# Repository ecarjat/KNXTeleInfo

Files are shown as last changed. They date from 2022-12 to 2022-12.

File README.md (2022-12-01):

# **French energy provider Enedis TeleInfo (TIC) KNX interface.**

Compatible with Enedis Linky meters in "Historic" mode, and "Blue" meters.

This is a fork of [etrinh software](https://github.com/etrinh/TeleInfoKNX) whose original design can be bought [here](https://www.tindie.com/products/zdi/knx-teleinfo/) 

This fork uses Raspberry [RP2040](https://www.raspberrypi.com/products/rp2040/) with a 64M-bit Serial Flash Memory and has a USB B Micro port to update the firmware.

# Firmware

The firmware has been refactored to split classes into their own files and adapt it to the rp2040.
It also leverages the latest version (as of 01/12/22) of [KNX Library](https://github.com/thelsing/knx) and in particular it's support for RP2040.

## **Features:**
- Activatable RealTime mode for real-time consumption monitoring/display.
- History of total Consumption (Current Year, Current Month, Today, Last Year, Last Month, Yesterday) (an external KNX Clock participant is required to provide accurate date and time).
- ETS5 configurable.
- Bus powered (10mA).

## **Usage:**
- Connect the device to the TeleInfo terminals (I1 I2) on the energy meter (No polarity).
- Connect the device to the KNX bus.
- To activate the device Programming Mode, click the "PROG / HRST".
- Configure device in ETS.
- To reset History, press the History Reset "PROG / HRST" Button more than 4 seconds.
- In case of over-current warning, the message "Depassement" (Group Object 43) is repeated every 10 seconds on the bus.

## **Led Interpretation:**
- Led Blinking (0.5s On/1.5s Off): TeleInfo data are receiving - **Device is working properly**.
- Led Continuously On: The device is in programming mode (it will automatically switch off after a delay of 15 minutes or a new press on the "PROG / HRST" button).
- Led Blinking (0.5s On/0.5s Off): The History is erased (happens when the "PROG / HRST" Button is pressed during more than 4 seconds).
- Led Off: The device is not receiving TeleInfo data, or is not configured with ETS5, or is not connected to the KNX Bus.

## **Group Objects:**
All "Consumption" Group Objects (from GO 7 to GO 24):

- Can be read to get the consumption index difference from the beginning and ending of the specified period.
- Can be written by the consumption index at the beginning of the corresponding period. It allows to specifically initialize the history from data provided by your energy provider. It is advised to set these indexes before affecting monitoring participants to these Group Objects.

## **Product Database:**
Click [here](https://github.com/etrinh/TeleInfoKNX/raw/master/ETS/teleinfo.knxprod) to download ETS5 product database (identified as KNX Association).

# Firmware upload
The Firmware can be uploaded directly through the USB port. On MacOS The firmware upload can be done by uncommenting this line in platform.io:
```
;upload_port = /Volumes/RPI-RP2/
```
This leverages the rp2040 embedded boot firmware. If the drive does not show pushing the reset button on the main board (SW3) while plugging in the usb should make it appear.
Once the firmware has been uploaded once, the serial port should become available.

# Hardware

## Sources
The hardware is build from a set of open source designs
[Adafruit ItsyBitsy rp2040](https://github.com/adafruit/Adafruit-ItsyBitsy-RP2040-PCB)
[Nano BCU](https://gitlab.com/knx-makerstuff/knx_microbcu2/-/wikis/NanoBCU)
[PiTInfo](https://github.com/hallard/teleinfo/tree/master/PiTInfo)
cobbled together on a board that needs to be cut in three parts and assembled.

## Geting the hardware

The folder hardware contain the kicad files and the gerber/bom/cpl files that can be sent to [JLCPCB](https://jlcpcb.com/).
The fabrication output is a board 

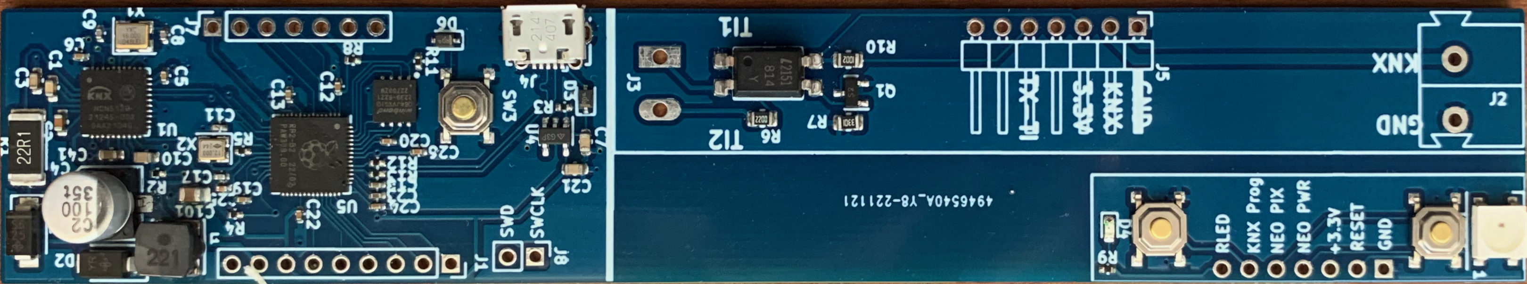
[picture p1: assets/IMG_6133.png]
[](assets/IMG_6133.png)

## Hardware assembly

The board then needs to be cut in three parts.

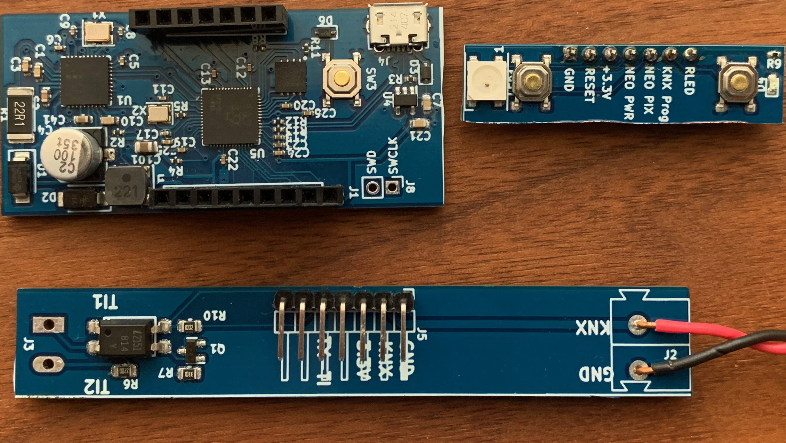
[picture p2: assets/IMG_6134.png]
[](assets/IMG_6134.png)

The assembly should be fairly self explanatory with teh silk screen. There are two unsused pins on the main board reserver for future use.

Once assembled the board looks like this

[](assets/IMG_6135.png)

And fits into a [DIN Rail Box Size 1 from RS PRO](https://docs.rs-online.com/575c/A700000006545717.pdf). This can be ordered [here](https://fr.rs-online.com/web/p/boitiers-rail-din/1947577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).

## Remarks

The NeoPixel on the top board is not used by this application and is not powered by the firmware.

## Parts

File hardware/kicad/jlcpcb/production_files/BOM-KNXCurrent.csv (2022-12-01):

Comment | Designator | Footprint | LCSC
16Mhz | X1 | Crystal_SMD_3225-4Pin_3.2x2.5mm | C13738
100nF/50V | C3 | C_0603_1608Metric | C14663
AP2112K-3.3 | U4 | SOT-23-5 | C51118
TVS SMA40 | D2 | D_SMA | C513490
1K | R11,R5,R9 | R_0402_1005Metric | C11702
LTV-814 | U2 | OPTO-SMD4 | C125118
NCN5120MNTWG | U1 | QFN-40-1EP_6x6mm_P0.5mm_EP4.6x4.6mm | C130364
USB_B_Micro | J4 | USB_Micro-B_Molex-105017-0001 | C136000
100nF/6.3V | C5,C6 | C_0402_1005Metric | C1525
18pF/50V | C11,C17 | C_0402_1005Metric | C1549
1uF/50V | C41 | C_0603_1608Metric | C15849
10uF/6.3V | C101 | C_0805_2012Metric | C15850
47nF/50V | C1 | C_0603_1608Metric | C1622
10K | R10 | R_0805_2012Metric | C17414
220R | R6 | R_0805_2012Metric | C17557
SS16 | D1 | D_SMA | C183023
RP2040 | U5 | QFN-56-1EP_7x7mm_P0.4mm_EP3.2x3.2mm | C2040
Red | D4 | D_0603_1608Metric | C2286
100uF/35V | C4 | CP_Elec_6.3x5.7 | C249982
22R | R12,R13 | R_0402_1005Metric | C25092
10k | R3,R4,R8 | R_0402_1005Metric | C25744
3K3 | R7 | R_0805_2012Metric | C26010
CJ2302 | Q1 | SOT-23 | C2910175
WS2812B3535 | LED1 | LED_WS2812B_PLCC4_5.0x5.0mm_P3.2mm | C2920042
W25Q64JVXGIQ | IC1 | SON80P400X400X50-9N | C2940195
100nF/50V | C12,C13,C19,C20,C22,C24,C25,C26 | C_0402_1005Metric | C307331
RESET | SW1,SW2,SW3 | SW_TS-1187A-B-A-B | C318884
10pF/50V | C8,C9 | C_0402_1005Metric | C32949
1R | R2 | R_0402_1005Metric | C332612
22R | R1 | R_2512_6332Metric | C421606
NSR0320 | D3,D6 | D_SOD-323 | C48192
220uH | L1 | IND_VLS5045EX-3R3N | C501936
12MHz | X2 | Crystal_SMD_2520-4Pin_2.5x2.0mm | C521567
1uF/25V | C18,C23 | C_0402_1005Metric | C52923
4.7nF/50V | C2 | C_0603_1608Metric | C53987
10uF/25V | C10,C21,C7 | C_0603_1608Metric | C96446
Debug | J8 | PinHeader_1x02_P2.54mm_Vertical
Conn_01x07_Male | J5 | PinHeader_1x07_P2.54mm_Horizontal
Conn_01x07_Female | J7 | PinSocket_1x07_P2.54mm_Vertical
KNX | J2 | KNX Male
Screw_Terminal_01x02 | J3 | TerminalBlock_Altech_AK300-2_P5.00mm
Conn_01x09_Female | J1 | PinSocket_1x09_P2.54mm_Vertical
Conn_01x07_Male | J6 | PinHeader_1x07_P2.54mm_Horizontal
SolderJumper_3_Bridged12 | JP2 | SolderJumper-3_P1.3mm_Bridged2Bar12_RoundedPad1.0x1.5mm_NumberLabels
Save to D11 | JP1 | SolderJumper-2_P1.3mm_Open_RoundedPad1.0x1.5mm

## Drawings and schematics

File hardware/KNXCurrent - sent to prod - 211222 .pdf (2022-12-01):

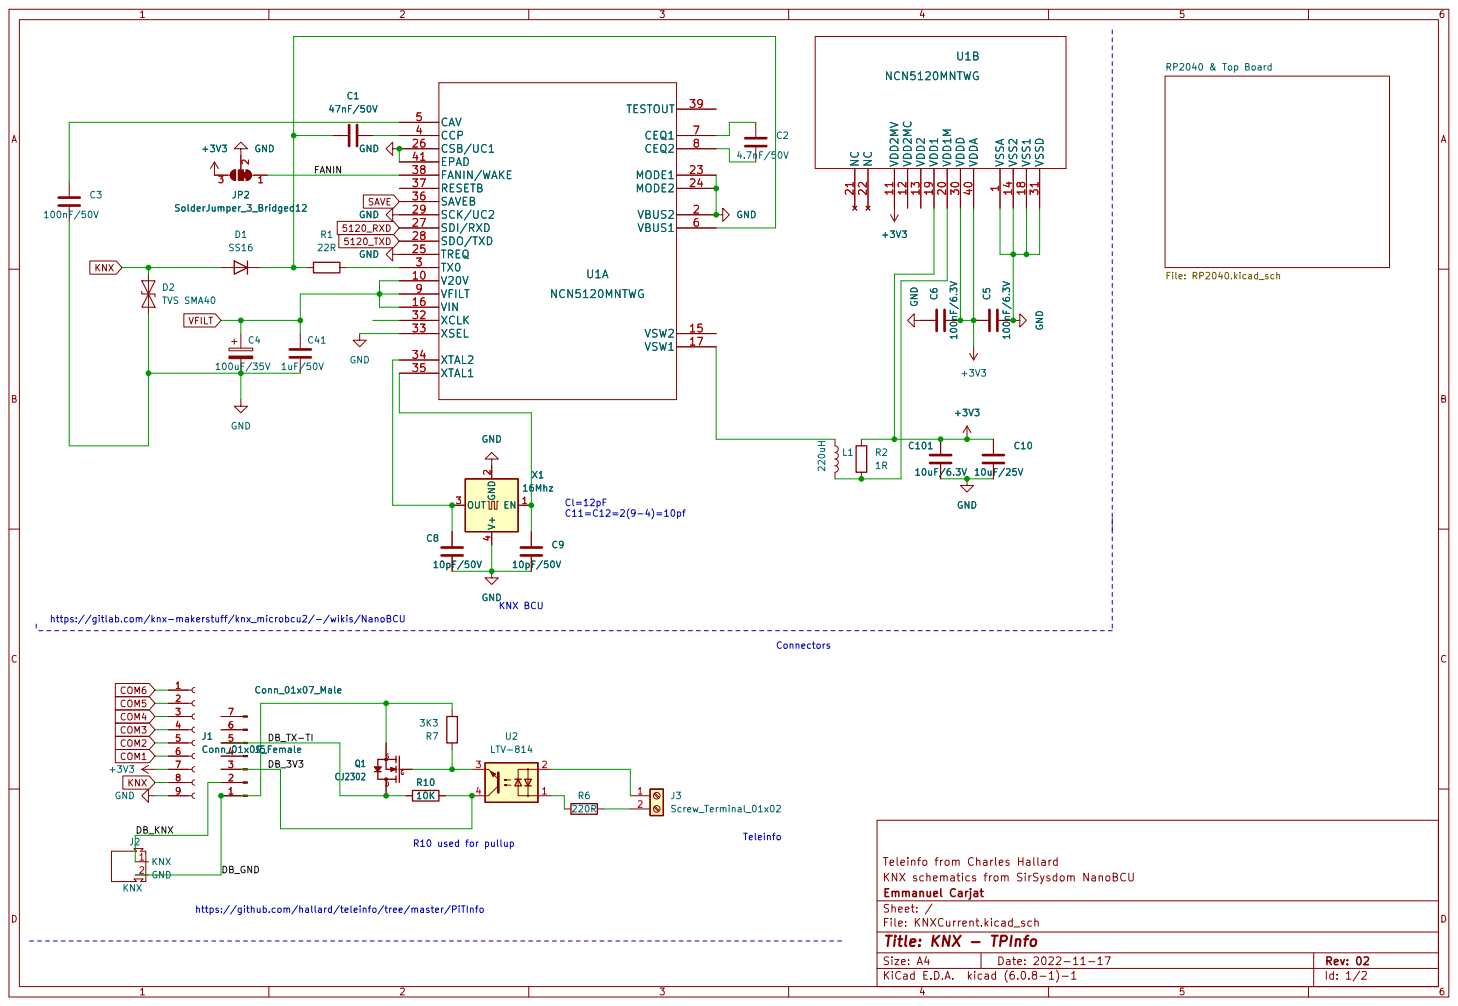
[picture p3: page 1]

1 VDD2MV 11 VDD2MC 12 VDD2 13 VSS2 14 VSS1 18 VDD1 19 VDD1M 20 NC 21 NC 22 VDDD 30 VSSD 31 VDDA 40 U1B NCN5120MNTWG

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

https://gitlab.com/knx-makerstuff/knx_microbcu2/-/wikis/NanoBCU

Teleinfo from Charles Hallard
KNX schematics from SirSysdom NanoBCU
File: KNXCurrent.kicad_sch Sheet: / Emmanuel Carjat

https://github.com/hallard/teleinfo/tree/master/PiTInfo

Id: 1/2 Title: KNX - TPInfo

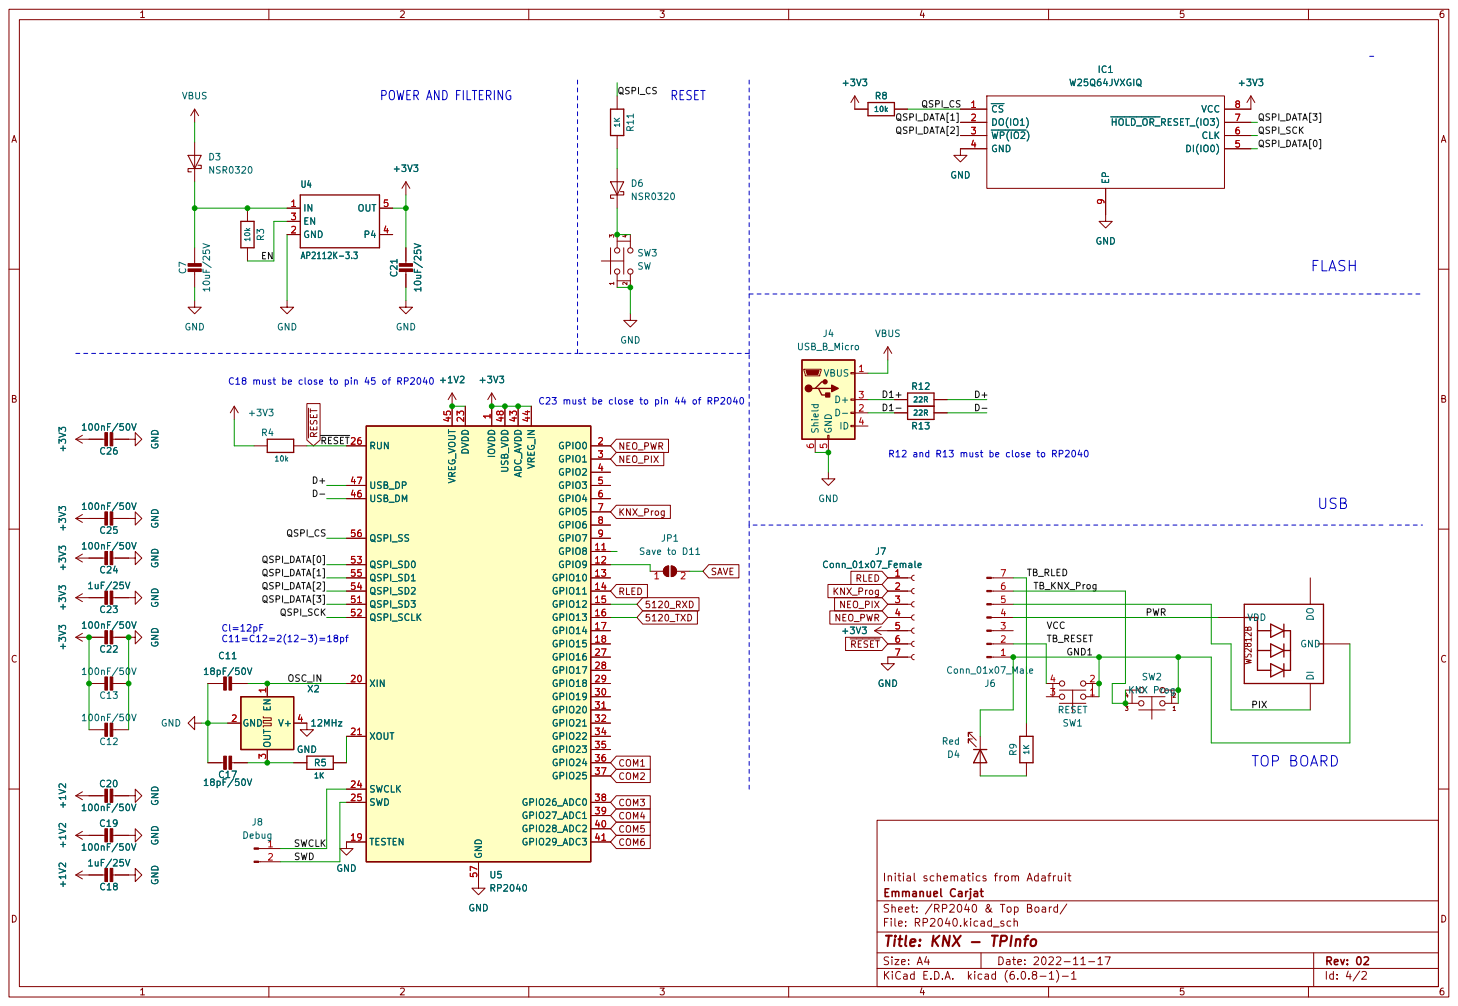
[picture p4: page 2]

C18 must be close to pin 45 of RP2040

C23 must be close to pin 44 of RP2040

1 GPIO8 11 GPIO9 12 GPIO10 13 GPIO11 14 GPIO12 15 GPIO13 16 GPIO14 17 GPIO15 18 TESTEN 19 GPIO0 2 XIN 20 XOUT 21 DVDD 23 SWCLK 24 SWD 25 RUN 26 GPIO16 27 GPIO17 28 GPIO18 29 GPIO1 3 GPIO19 30 GPIO20 31 GPIO21 32 GPIO22 34 GPIO23 35 GPIO24 36 GPIO25 37 GPIO26_ADC0 38 GPIO27_ADC1 39 GPIO2 4 GPIO28_ADC2 40 GPIO29_ADC3 41 ADC_AVDD 43 VREG_IN 44 VREG_VOUT 45 USB_DM 46 USB_DP 47 USB_VDD 48 GPIO3 5 QSPI_SD3 51 QSPI_SCLK 52 QSPI_SD0 53 QSPI_SD2 54 QSPI_SD1 55 QSPI_SS 56 GND 57 GPIO4 6 GPIO5 7 GPIO6 8 GPIO7 9 GND GND

1 GPIO8 11 GPIO9 12 GPIO10 13 GPIO11 14 GPIO12 15 GPIO13 16 GPIO14 17 GPIO15 18 TESTEN 19 GPIO0 2 XIN 20 XOUT 21 DVDD 23 SWCLK 24 SWD 25 RUN 26 GPIO16 27 GPIO17 28 GPIO18 29 GPIO1 3 GPIO19 30 GPIO20 31 GPIO21 32 GPIO22 34 GPIO23 35 GPIO24 36 GPIO25 37 GPIO26_ADC0 38 GPIO27_ADC1 39 GPIO2 4 GPIO28_ADC2 40 GPIO29_ADC3 41 ADC_AVDD 43 VREG_IN 44 VREG_VOUT 45 USB_DM 46 USB_DP 47 USB_VDD 48 GPIO3 5 QSPI_SD3 51 QSPI_SCLK 52 QSPI_SD0 53 QSPI_SD2 54 QSPI_SD1 55 QSPI_SS 56 GND 57 GPIO4 6 GPIO5 7 GPIO6 8 GPIO7 9 U5RP2040 R91K

Initial schematics from Adafruit C19

Emmanuel Carjat
Sheet: /RP2040 & Top Board/
File: RP2040.kicad_sch
Id: 4/2 Title: KNX - TPInfo

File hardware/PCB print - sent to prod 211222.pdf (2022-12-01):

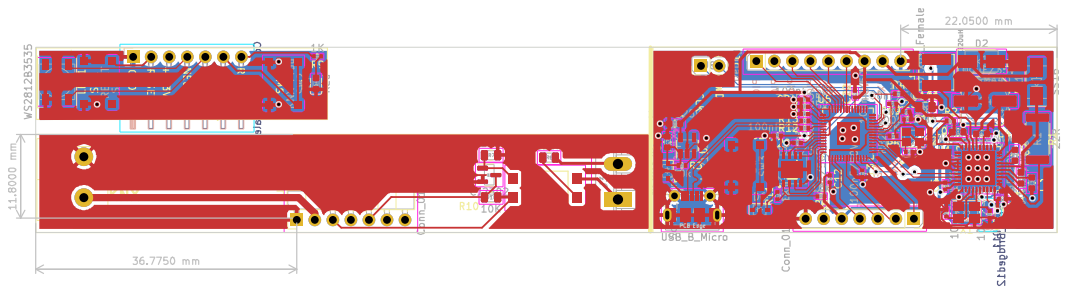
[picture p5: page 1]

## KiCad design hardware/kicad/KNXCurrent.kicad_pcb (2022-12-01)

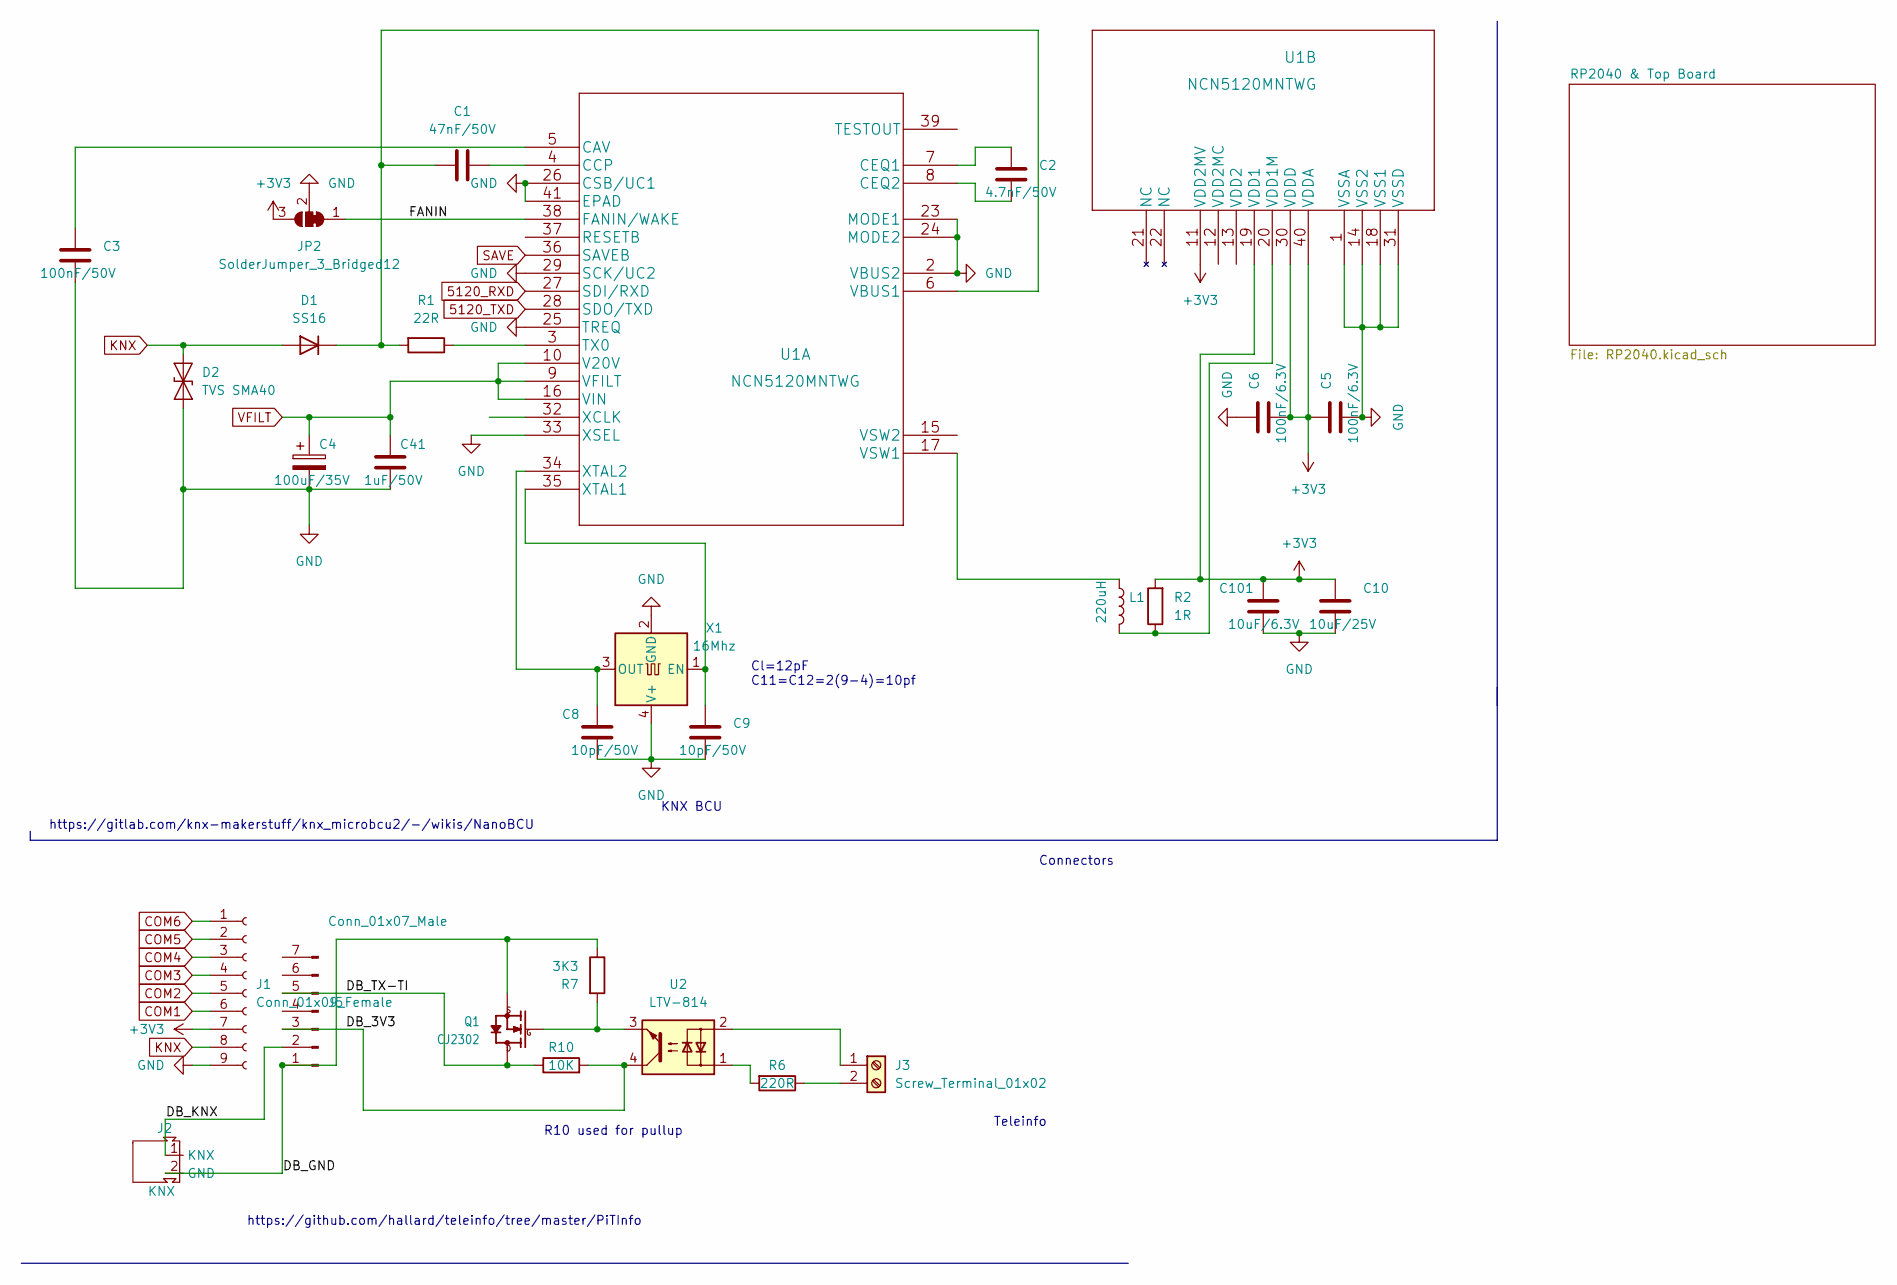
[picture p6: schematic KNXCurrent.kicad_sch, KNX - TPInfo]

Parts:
C1: 47nF/50V; C_0603_1608Metric; LCSC C1622
C2: 4.7nF/50V; C_0603_1608Metric; LCSC C53987
C3: 100nF/50V; C_0603_1608Metric; LCSC C14663
C4: 100uF/35V; CP_Elec_6.3x5.7; LCSC C249982
C5, C6: 100nF/6.3V; C_0402_1005Metric; LCSC C1525
C8, C9: 10pF/50V; C_0402_1005Metric; LCSC C32949
C10: 10uF/25V; C_0603_1608Metric; LCSC C96446
C41: 1uF/50V; C_0603_1608Metric; LCSC C15849
C101: 10uF/6.3V; C_0805_2012Metric; LCSC C15850
D1: SS16; D_SMA; LCSC C183023
D2: TVS SMA40; D_SMA; LCSC C513490
J1: Conn_01x09_Female; PinSocket_1x09_P2.54mm_Vertical
J2: KNX; KNX Male
J3: Screw_Terminal_01x02; TerminalBlock_Altech_AK300-2_P5.00mm
J5: Conn_01x07_Male; PinHeader_1x07_P2.54mm_Horizontal
JP2: SolderJumper_3_Bridged12; SolderJumper-3_P1.3mm_Bridged2Bar12_RoundedPad1.0x1.5mm_Num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
L1: 220uH; IND_VLS5045EX-3R3N; LCSC C501936
Q1: CJ2302; SOT-23; LCSC C2910175
R1: 22R; R_2512_6332Metric; LCSC C421606
R2: 1R; R_0402_1005Metric; LCSC C332612
R6: 220R; R_0805_2012Metric; LCSC C17557
R7: 3K3; R_0805_2012Metric; LCSC C26010
R10: 10K; R_0805_2012Metric; LCSC C17414
U1: NCN5120MNTWG; QFN-40-1EP_6x6mm_P0.5mm_EP4.6x4.6mm; LCSC C130364
U2: LTV-814; OPTO-SMD4; LCSC C125118
X1: 16Mhz; Crystal_SMD_3225-4Pin_3.2x2.5mm; LCSC C13738

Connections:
5120_RXD: U1.27 (SDI/RXD); also elsewhere on the board
5120_TXD: U1.28 (SDO/TXD); also elsewhere on the board
+3V3: C5.1, C6.2, C10.1, C101.1, J1.7, JP2.3 (B), R2.2, U1.11 (VDD2MV), U1.19 (VDD1), U1.30 (VDDD), U1.40 (VDDA); also elsewhere on the board
/DB_3V3: J5.3, R10.2, U2.4
/DB_GND: J2.2 (GND), J5.1, Q1.2 (S), R7.1
/DB_KNX: J2.1 (KNX), J5.2
/DB_TX-TI: J5.5, Q1.3 (D), R10.1
/FANIN: JP2.1 (A), U1.38 (FANIN/WAKE)
COM1: J1.6; also elsewhere on the board
COM2: J1.5; also elsewhere on the board
COM3: J1.4; also elsewhere on the board
COM4: J1.3; also elsewhere on the board
COM5: J1.2; also elsewhere on the board
COM6: J1.1; also elsewhere on the board
GND: C3.2, C4.2, C5.2, C6.1, C8.2, C9.2, C10.2, C41.2, C101.2, D2.2 (A2), J1.9, JP2.2 (C), U1.1 (VSSA), U1.2 (VBUS2), U1.14 (VSS2), U1.18 (VSS1), U1.23 (MODE1), U1.24 (MODE2), U1.25 (TREQ), U1.26 (CSB/UC1), U1.29 (SCK/UC2), U1.31 (VSSD), U1.33 (XSEL), U1.41 (EPAD), X1.2 (GND), X1.4 (V+); also elsewhere on the board
KNX: D1.2 (A), D2.1 (A1), J1.8
unnamed: C1.1, D1.1 (K), R1.2, U1.6 (VBUS1)
unnamed: C1.2, U1.4 (CCP)
unnamed: C2.1, U1.7 (CEQ1)
unnamed: C2.2, U1.8 (CEQ2)
unnamed: C3.1, U1.5 (CAV)
unnamed: C8.1, U1.34 (XTAL2), X1.3 (OUT)
unnamed: C9.1, U1.35 (XTAL1), X1.1 (EN)
unnamed: J3.1, U2.2
unnamed: J3.2, R6.1
unnamed: L1.1, U1.17 (VSW1)
unnamed: L1.2, R2.1, U1.20 (VDD1M)
unnamed: Q1.1 (G), R7.2, U2.3
unnamed: R1.1, U1.3 (TX0)
unnamed: R6.2, U2.1
SAVE: U1.36 (SAVEB); also elsewhere on the board
VFILT: C4.1, C41.1, U1.9 (VFILT), U1.10 (V20V), U1.16 (VIN)

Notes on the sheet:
Connectors
R10 used for pullup
https://github.com/hallard/teleinfo/tree/master/PiTInfo
Teleinfo
Cl=12pF C11=C12=2(9-4)=10pf
KNX BCU
https://gitlab.com/knx-makerstuff/knx_microbcu2/-/wikis/NanoBCU

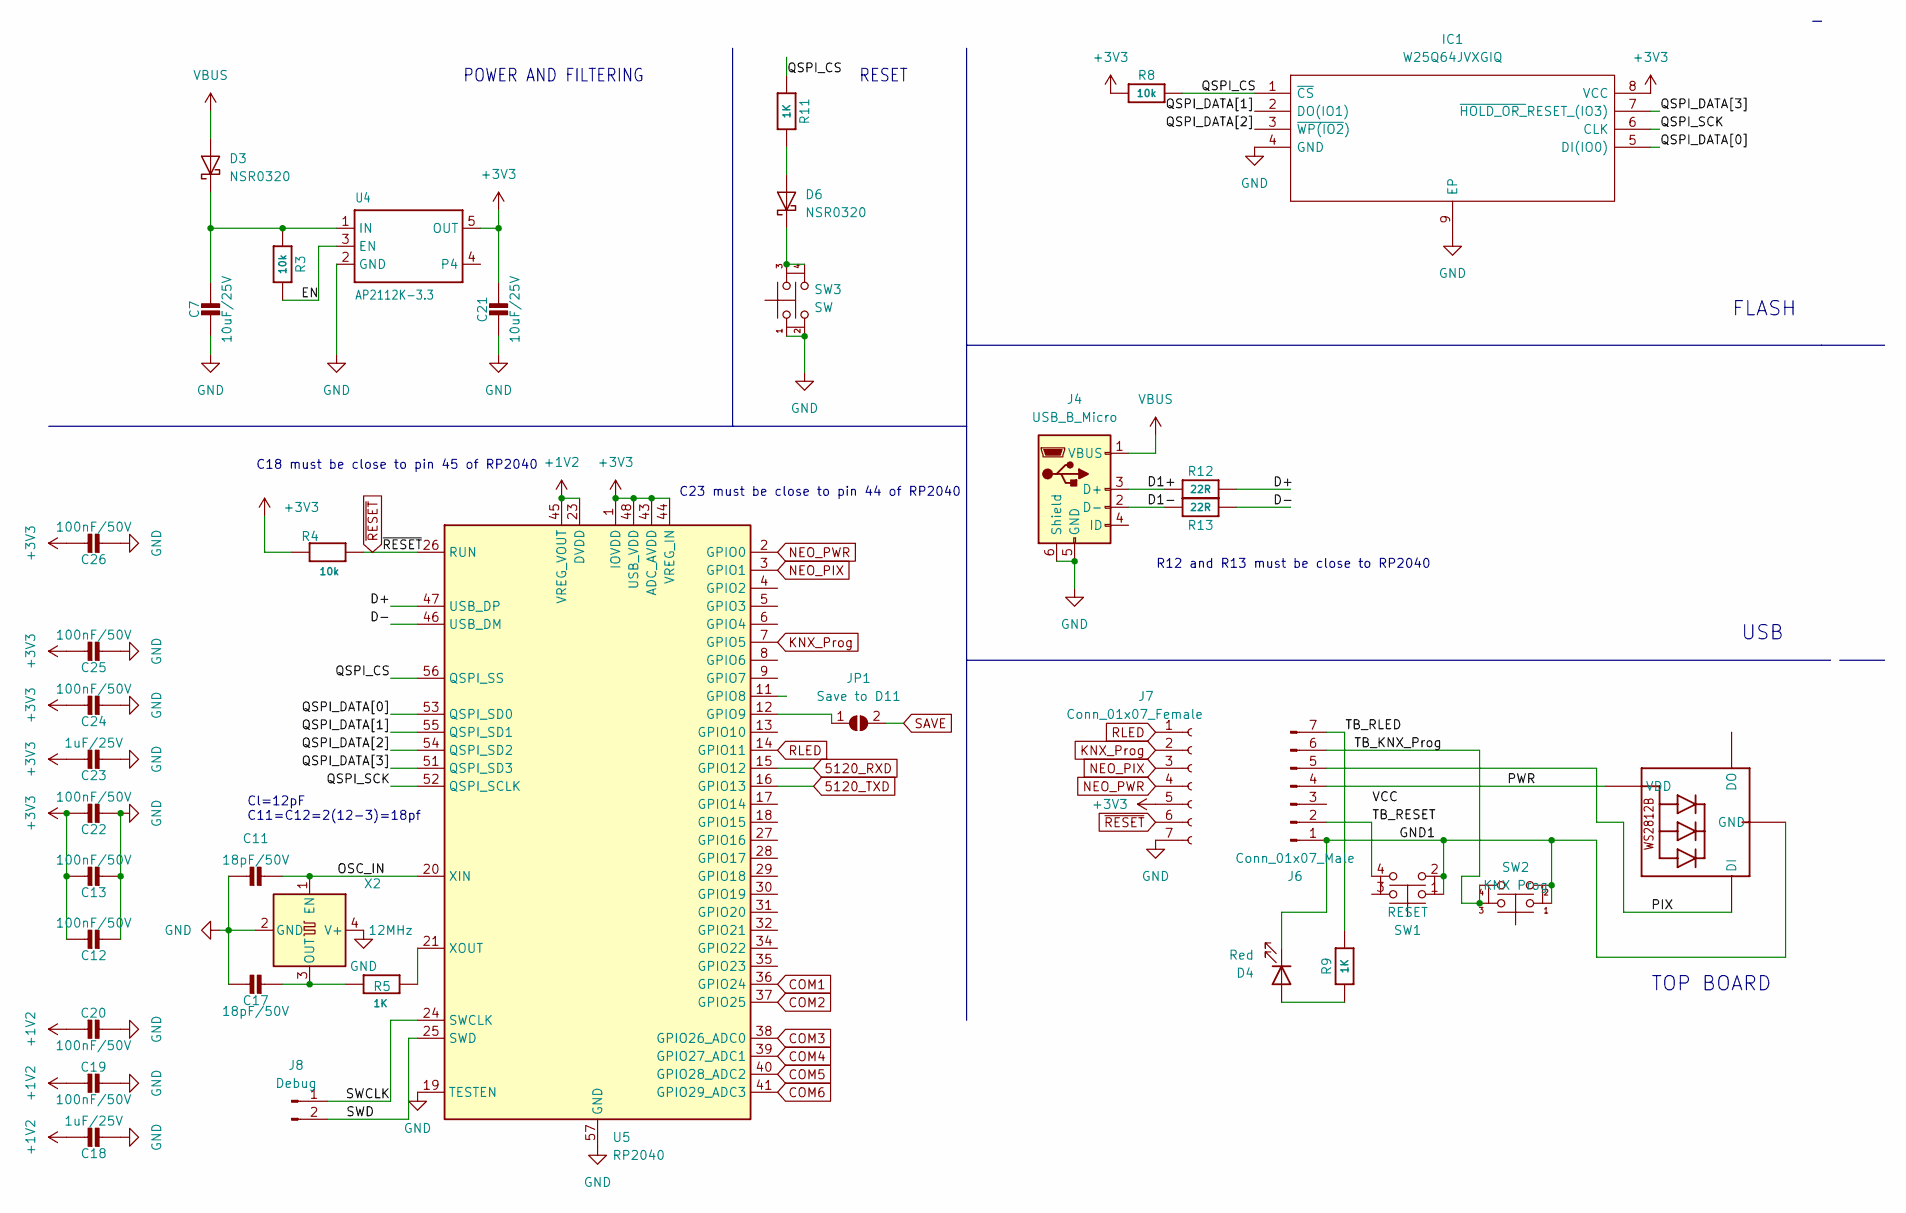
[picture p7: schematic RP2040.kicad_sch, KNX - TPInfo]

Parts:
C7, C21: 10uF/25V; C_0603_1608Metric; LCSC C96446
C11, C17: 18pF/50V; C_0402_1005Metric; LCSC C1549
C12, C13, C19, C20, C22, C24, C25, C26: 100nF/50V; C_0402_1005Metric; LCSC C307331
C18, C23: 1uF/25V; C_0402_1005Metric; LCSC C52923
D3, D6: NSR0320; D_SOD-323; LCSC C48192
D4: Red; D_0603_1608Metric; LCSC C2286
IC1: W25Q64JVXGIQ; SON80P400X400X50-9N; Manufacturer_Part_Number W25Q64JVXGIQ; LCSC C2940195
J4: USB_B_Micro; USB_Micro-B_Molex-105017-0001; LCSC C136000
J6: Conn_01x07_Male; PinHeader_1x07_P2.54mm_Horizontal
J7: Conn_01x07_Female; PinSocket_1x07_P2.54mm_Vertical
J8: Debug; PinHeader_1x02_P2.54mm_Vertical
JP1: Save to D11; SolderJumper-2_P1.3mm_Open_RoundedPad1.0x1.5mm
LED1: WS2812B3535; LED_WS2812B_PLCC4_5.0x5.0mm_P3.2mm; LCSC C2920042
R3, R4, R8: 10k; R_0402_1005Metric; LCSC C25744
R5, R9, R11: 1K; R_0402_1005Metric; LCSC C11702
R12, R13: 22R; R_0402_1005Metric; LCSC C25092
SW1: RESET; SW_TS-1187A-B-A-B; LCSC C318884
SW2: KNX Prog; SW_TS-1187A-B-A-B; LCSC C318884
SW3: SW; SW_TS-1187A-B-A-B; LCSC C318884
U4: AP2112K-3.3; SOT-23-5; LCSC C51118
U5: RP2040; QFN-56-1EP_7x7mm_P0.4mm_EP3.2x3.2mm; LCSC C2040
X2: 12MHz; Crystal_SMD_2520-4Pin_2.5x2.0mm; LCSC C521567

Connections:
5120_RXD: U5.15 (GPIO12); also elsewhere on the board
5120_TXD: U5.16 (GPIO13); also elsewhere on the board
+1V2: C18.1, C19.2, C20.2, U5.23 (DVDD), U5.45 (VREG_VOUT), U5.50 (DVDD)
+3V3: C12.1, C13.1, C21.1, C22.1, C23.1, C24.1, C25.1, C26.1, IC1.8 (VCC), J7.5, R4.1, R8.1, U4.5 (OUT), U5.1 (IOVDD), U5.10 (IOVDD), U5.22 (IOVDD), U5.33 (IOVDD), U5.42 (IOVDD), U5.43 (ADC_AVDD), U5.44 (VREG_IN), U5.48 (USB_VDD), U5.49 (IOVDD); also elsewhere on the board
/RP2040 & Top Board/D1+: J4.3 (D+), R12.1
/RP2040 & Top Board/D1-: J4.2 (D-), R13.1
/RP2040 & Top Board/D+: R12.2, U5.47 (USB_DP)
/RP2040 & Top Board/D-: R13.2, U5.46 (USB_DM)
/RP2040 & Top Board/EN: R3.2, U4.3 (EN)
/RP2040 & Top Board/GND1: D4.1 (K), J6.1, LED1.3 (GND), SW1.1, SW1.2, SW2.1, SW2.2
/RP2040 & Top Board/OSC_IN: C11.2, U5.20 (XIN), X2.1 (EN)
/RP2040 & Top Board/PIX: J6.5, LED1.4 (DI)
/RP2040 & Top Board/PWR: J6.4, LED1.1 (VDD)
/RP2040 & Top Board/QSPI_CS: IC1.1 (~CS), R8.2, R11.1, U5.56 (QSPI_SS)
/RP2040 & Top Board/QSPI_DATA[0]: IC1.5 (DI(IO0)), U5.53 (QSPI_SD0)
/RP2040 & Top Board/QSPI_DATA[1]: IC1.2 (DO(IO1)), U5.55 (QSPI_SD1)
/RP2040 & Top Board/QSPI_DATA[2]: IC1.3 (~WP(IO2)), U5.54 (QSPI_SD2)
/RP2040 & Top Board/QSPI_DATA[3]: IC1.7 (~HOLD_OR_RESET_(IO3)), U5.51 (QSPI_SD3)
/RP2040 & Top Board/QSPI_SCK: IC1.6 (CLK), U5.52 (QSPI_SCLK)
/RP2040 & Top Board/SWCLK: J8.1, U5.24 (SWCLK)
/RP2040 & Top Board/SWD: J8.2, U5.25 (SWD)
/RP2040 & Top Board/TB_KNX_Prog: J6.6, SW2.3, SW2.4
/RP2040 & Top Board/TB_RESET: J6.2, SW1.4
/RP2040 & Top Board/TB_RLED: J6.7, R9.2
COM1: U5.36 (GPIO24); also elsewhere on the board
COM2: U5.37 (GPIO25); also elsewhere on the board
COM3: U5.38 (GPIO26_ADC0); also elsewhere on the board
COM4: U5.39 (GPIO27_ADC1); also elsewhere on the board
COM5: U5.40 (GPIO28_ADC2); also elsewhere on the board
COM6: U5.41 (GPIO29_ADC3); also elsewhere on the board
GND: C7.2, C11.1, C12.2, C13.2, C17.1, C18.2, C19.1, C20.1, C21.2, C22.2, C23.2, C24.2, C25.2, C26.2, IC1.4 (GND), IC1.9 (EP), J4.5 (GND), J4.6 (Shield), J7.7, SW3.1, SW3.2, U4.2 (GND), U5.19 (TESTEN), U5.57 (GND), X2.2 (GND), X2.4 (V+); also elsewhere on the board
KNX_Prog: J7.2, U5.7 (GPIO5)
NEO_PIX: J7.3, U5.3 (GPIO1)
NEO_PWR: J7.4, U5.2 (GPIO0)
unnamed: C7.1, D3.1 (K), R3.1, U4.1 (IN)
unnamed: C17.2, R5.1, X2.3 (OUT)
unnamed: D4.2 (A), R9.1
unnamed: D6.1 (K), SW3.3, SW3.4
unnamed: D6.2 (A), R11.2
unnamed: JP1.1 (A), U5.12 (GPIO9)
unnamed: R5.2, U5.21 (XOUT)
RLED: J7.1, U5.14 (GPIO11)
SAVE: JP1.2 (B); also elsewhere on the board
VBUS: D3.2 (A), J4.1 (VBUS)
~RESET: J7.6, R4.2, U5.26 (RUN)

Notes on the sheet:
C23 must be close to pin 44 of RP2040
POWER AND FILTERING
R12 and R13 must be close to RP2040
USB
C18 must be close to pin 45 of RP2040
TOP BOARD
Cl=12pF C11=C12=2(12-3)=18pf
FLASH
RESET

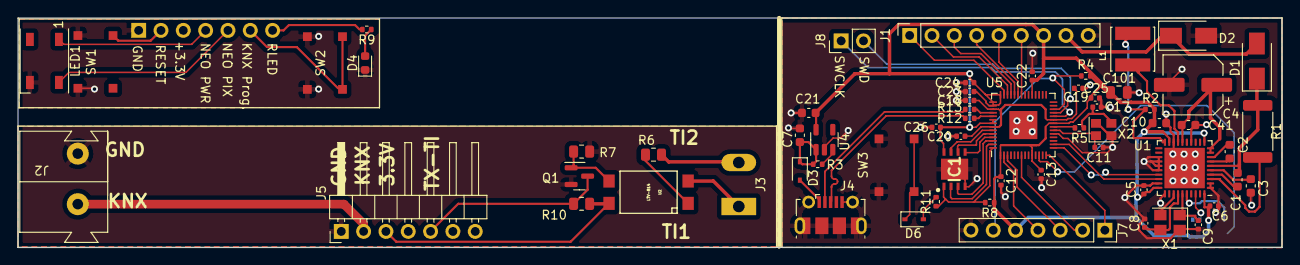
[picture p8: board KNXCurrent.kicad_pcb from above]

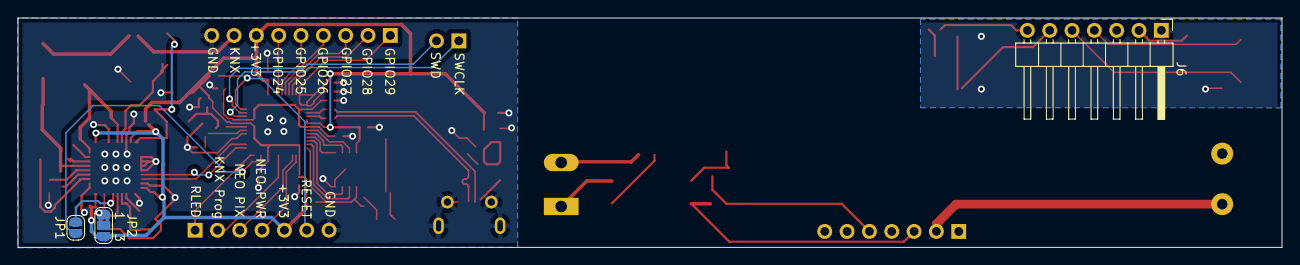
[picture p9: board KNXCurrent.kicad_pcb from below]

Board: 2 copper layers, 143.8 x 26.1 mm, 66 parts (3 on the bottom side), 66 nets.

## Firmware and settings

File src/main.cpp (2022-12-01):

/*
 * TeleInfo KNX
 *  Can be used with French TeleInfo systems
 *  Compatible with Linky in "Historic" mode and "Blue" electric meters
 *  GPL-3.0 License
 * Copyright 2020-2021 ZapDesign Innovative - Author: Eric Trinh
 */

#include <Arduino.h>
#include <knx.h>

#include <hardware/uart.h>

#include <pico/stdlib.h>
#include <hardware/pll.h>
#include <hardware/clocks.h>
#include <hardware/structs/pll.h>
#include <hardware/structs/clocks.h>

#include "RTCKnx.h"
#include "TeleInfo.h"

#define VERSION_MAJOR 1
#define VERSION_MINOR 0
#define VERSION_REVISION 0

#define PIN_PROG_SWITCH 5
#define PIN_PROG_LED 11
#define PROG_TIMEOUT (15 * 60 * 1000) // 15 mins
#define PIN_TPUART_RX 13              // stm32 knx uses Serial2 (pins 16,17)
#define PIN_TPUART_TX 12

#define TELEINFO_UART_SPEED 1200        //
#define TELEINFO_UART_CONFIG SERIAL_7E1 // SERIAL_7E1
#define TELEINFO_UART_RX 25
#define TELEINFO_UART_TX 24

#define HISTORY_RESET_PROG_SWITCH_DELAY 4000  // 4s
#define HISTORY_RESET_LED_BLINKING_PERIOD 512 // 0.512s
#define RECEPTION_LED_BLINKING_PERIOD 512     // 0.512s

// Restore ram after reset (brownout)
#define INIT_MASK 0x12345678
volatile uint32_t Inited __attribute__((section(".noinit")));

uint8_t rtcHolder[sizeof(RTCKnx)] __attribute__((section(".noinit")));
RTCKnx &rtc = *(RTCKnx *)rtcHolder;

uint8_t teleinfoHolder[sizeof(TeleInfo)] __attribute__((section(".noinit")));
TeleInfo &teleinfo = *(TeleInfo *)teleinfoHolder;

extern "C" void SystemClock_Config(void)
{
    // Nothing for default 4MHz MSI Clock
    // Required to downclock the 80MHz clock to be below 4096 * 16 * 1200 (TeleInfo BaudRate) due to limitation in UART_BRR 12bit register
}

static SerialUART serialTpuart(uart0, PIN_TPUART_TX, PIN_TPUART_RX);
static SerialUART serialTeleInfo(uart1, TELEINFO_UART_TX, TELEINFO_UART_RX);

void setup()
{

    // Serial.begin(115200);
    // ArduinoPlatform::SerialDebug = &Serial;
    // while(!Serial){
    //      delay(10);
    //  }
    //  delay(300);
    //  Serial.println("Loading ....");

    if (Inited != INIT_MASK)
    {
        new (&rtc) RTCKnx();
        new (&teleinfo) TeleInfo(&rtc, &serialTeleInfo, TELEINFO_UART_SPEED, TELEINFO_UART_CONFIG);
        Inited = INIT_MASK;
    }

   


    knx.platform().knxUart(&serialTpuart);
    knx.ledPin(PIN_PROG_LED);
    knx.ledPinActiveOn(HIGH);
    knx.buttonPin(PIN_PROG_SWITCH);


    // Init device
    knx.version((VERSION_MAJOR << 6) | (VERSION_MINOR & 0x3F)); // PID_VERSION
    knx.orderNumber((const uint8_t *)"ZDI-TINFO1");             // PID_ORDER_INFO
    knx.manufacturerId(0xfa);                                   // PID_SERIAL_NUMBER (2 first bytes) - 0xfa for KNX Association
    knx.hardwareType((const uint8_t *)"M-07B0");                // PID_HARDWARE_TYPE

    // read adress table, association table, groupobject table and parameters from eeprom
    knx.readMemory();
    
    if (knx.configured())
    {
        rtc.init(0, 0);
        teleinfo.init(RTCKnx::SIZEPARAMS, RTCKnx::NBGO);
        rtc.setNotifier(std::bind(&TeleInfo::newDate, &teleinfo, std::placeholders::_1));
        // attachInterrupt(PIN_TPUART_SAVE, std::bind(&TeleInfo::saveHistory, &teleinfo), LOW);    // 2ms to save history before shutdown - likely not enough
    }

    // start the framework.
    knx.start();

}

int led = false;
bool progButtonState;
void loop()
{
    
    // don't delay here too much. Otherwise you might loose packages or mess up the timing with ETS
    knx.loop();
    // only run the application code if the device was configured with ETS
    if (knx.configured())
    {
        teleinfo.loop();
        rtc.loop();
    }
    

    uint32_t currentMillis = rtc.millis();
    PinStatus prog_pin = digitalRead(PIN_PROG_SWITCH);
    if(prog_pin == HIGH){
        progButtonState = false;
    }
    else {
        progButtonState = true;
    }


        // Handle Reset History by long prog button press
        static uint32_t progButtonPressedTimer = 0;
        static bool historyReset = false;

        if (!progButtonState && currentMillis - progButtonPressedTimer > 200) {
            progButtonPressedTimer = 0;
            if (historyReset) {
                digitalWrite(PIN_PROG_LED, LOW);
            }
            historyReset = false;
        }
        else {
            if (progButtonPressedTimer == 0) {
                progButtonPressedTimer = currentMillis;
            }
            else {
                uint32_t delay = currentMillis - progButtonPressedTimer;
                if (delay > HISTORY_RESET_PROG_SWITCH_DELAY) {
                    if (!historyReset) {
                        knx.progMode(false);
                        teleinfo.resetHistory();
                        historyReset = true;
                    }
                    if (historyReset) {
                        digitalWrite(PIN_PROG_LED, (delay/HISTORY_RESET_LED_BLINKING_PERIOD)&1);
                    }
                }
            }
        }

        // Handle Prog Mode timeout
        static uint32_t timerProgMode = 0;
        if (knx.progMode()) {
            if (timerProgMode == 0) {
                timerProgMode = currentMillis;
            }
            else {
                if (currentMillis - timerProgMode > PROG_TIMEOUT) {
                    knx.progMode(false);
                    timerProgMode = 0;
                }
            }
        }
        else {
            timerProgMode = 0;
        }


    // Handle reception blinking led (2s cycle with 0.5s On while receiving Teleinfo data)
    
    if (!knx.progMode() && !progButtonState)
    {
        //Serial.println(currentMillis - teleinfo.lastReception());
        if (currentMillis - teleinfo.lastReception() < RECEPTION_LED_BLINKING_PERIOD * 2)
        {
            digitalWrite(PIN_PROG_LED, ((currentMillis / RECEPTION_LED_BLINKING_PERIOD) & 3) == 0);
        }
        else
        {
            digitalWrite(PIN_PROG_LED, LOW);
        }
    }
    
}

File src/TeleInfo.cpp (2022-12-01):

#include <Arduino.h>
#include <knx.h>
#include <EEPROM.h>
#include "TeleInfo.h"

#define FOURCC(a, b, c, d) (((((uint32_t)(a)) << 24) | (((uint32_t)(b)) << 16) | (((uint32_t)(c)) << 8) | (d)))

TeleInfo::TeleInfo(RTCKnx *_rtc, SerialUART *suart, unsigned long _baud, uint16_t _config) : mSerial(*suart), rtc(*_rtc)
{
    speed = _baud;
    config = _config;
}

KNXValue TeleInfo::value(const TeleInfo::TeleInfoDataStruct &val)
{
    switch (val.conf->type)
    {
    default:
    case TeleInfoDataType::INT:
        return KNXValue(val.value.num);
    case TeleInfoDataType::STRING:
        return KNXValue(val.value.str);
    case TeleInfoDataType::OPTARIF:
        switch (val.value.num & 0xffffff00)
        {
        case FOURCC('B', 'A', 'S', 0) /*BASE*/:
        default:
            return KNXValue((uint8_t)0);
        case FOURCC('H', 'C', '.', 0) /*HC..*/:
            return KNXValue((uint8_t)1);
        case FOURCC('E', 'J', 'P', 0) /*EJP.*/:
            return KNXValue((uint8_t)2);
        case FOURCC('B', 'B', 'R', 0) /*BBRx*/:
            return KNXValue((uint8_t)(val.value.num & 0x3f));
            //                                  - Bit 5: toujours 1
            //                                  - Bit 4-3: programme circuit 1: 01-11 _ programme A-C
            //                                  - Bit 2-0: programme circuit 2: 000-111 _ programme P0-P7
        }
    case TeleInfoDataType::PTEC:
        switch (val.value.num)
        {
        case FOURCC('T', 'H', '.', '.') /*Toutes les Heures*/:
        default:
            return KNXValue((uint8_t)0);
        case FOURCC('H', 'C', '.', '.') /*Heures Creuses*/:
            return KNXValue((uint8_t)1);
        case FOURCC('H', 'P', '.', '.') /*Heures Pleines*/:
            return KNXValue((uint8_t)2);
        case FOURCC('H', 'N', '.', '.') /*Heures Normales*/:
            return KNXValue((uint8_t)3);
        case FOURCC('P', 'M', '.', '.') /*Heures de Pointe Mobile*/:
            return KNXValue((uint8_t)4);
        case FOURCC('H', 'C', 'J', 'B') /*Heures Creuses Jours Bleus*/:
            return KNXValue((uint8_t)5);
        case FOURCC('H', 'C', 'J', 'W') /*Heures Creuses Jours Blancs*/:
            return KNXValue((uint8_t)6);
        case FOURCC('H', 'C', 'J', 'R') /*Heures Creuses Jours Rouges*/:
            return KNXValue((uint8_t)7);
        case FOURCC('H', 'P', 'J', 'B') /*Heures Pleines Jours Bleus*/:
            return KNXValue((uint8_t)8);
        case FOURCC('H', 'P', 'J', 'W') /*Heures Pleines Jours Blancs*/:
            return KNXValue((uint8_t)9);
        case FOURCC('H', 'P', 'J', 'R') /*Heures Pleines Jours Rouges*/:
            return KNXValue((uint8_t)10);
        }
    case TeleInfoDataType::DEMAIN:
        switch (val.value.num)
        {
        case FOURCC('-', '-', '-', '-'):
        default:
            return KNXValue((uint8_t)0);
        case FOURCC('B', 'L', 'E', 'U'):
            return KNXValue((uint8_t)1);
        case FOURCC('B', 'L', 'A', 'N'):
            return KNXValue((uint8_t)2);
        case FOURCC('R', 'O', 'U', 'G'):
            return KNXValue((uint8_t)3);
        }
    case TeleInfoDataType::HHPHC:
        return KNXValue((uint8_t)val.value.num);
    }
}

bool TeleInfo::value(TeleInfo::TeleInfoDataStruct &val, const char *begin, const char *end)
{
    begin += val.conf->keySize;
    const char *vEnd = begin + val.conf->size;
    if (vEnd < end)
    {
        if (val.conf->type == TeleInfo::TeleInfoDataType::STRING)
        {
            const uint8_t size = val.conf->size;
            if (memcmp(val.value.str, begin, size) != 0)
            {
                memcpy(val.value.str, begin, size);
                val.value.str[size] = '\0';
                return true;
            }
        }
        else if (val.conf->type == TeleInfo::TeleInfoDataType::INT)
        {
            uint32_t _value = 0;
            for (; begin != vEnd; ++begin)
            {
                const unsigned char v = (const unsigned char)(*begin - '0');
                if (v > 9)
                    break;
                _value = _value * 10 + v;
            }
            if (val.value.num != _value)
            {
                val.value.num = _value;
                return true;
            }
        }
        else
        {
            uint32_t _value = 0;
            for (; begin != vEnd; ++begin)
            {
                _value = (_value << 8) | *(uint8_t *)begin;
            }
            if (val.value.num != _value)
            {
                val.value.num = _value;
                return true;
            }
        }
    }
    return false;
}

bool TeleInfo::validChecksum(const char *begin, const char *end)
{
    uint16_t sum = 0;
    uint8_t spaceFound = 0;
    for (; begin != end; ++begin)
    {
        const char c = *begin;
        if (c == ' ')
        {
            ++spaceFound;
        }
        else if (spaceFound == 2)
        {
            // checksum after second space
            return (((uint8_t)(sum - ' ') & 0x3F) + 0x20) == c;
        }
        sum += c;
    }
    return false;
}

uint32_t TeleInfo::simpleChecksum(const char *str)
{
    uint32_t result = 0;
    while (*str)
        result += result + *str++;
    return result;
}
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
